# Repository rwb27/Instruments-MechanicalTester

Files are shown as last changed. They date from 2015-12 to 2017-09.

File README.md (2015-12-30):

# OpenLabTools Mechanical Testing Machine

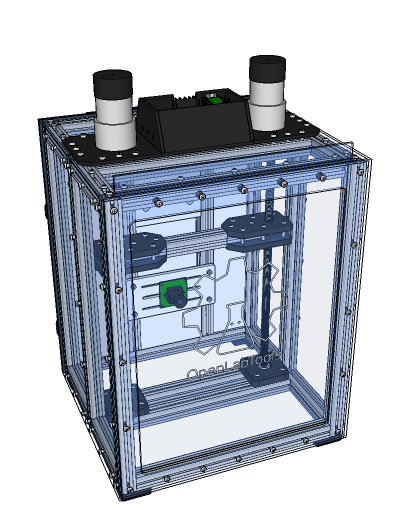
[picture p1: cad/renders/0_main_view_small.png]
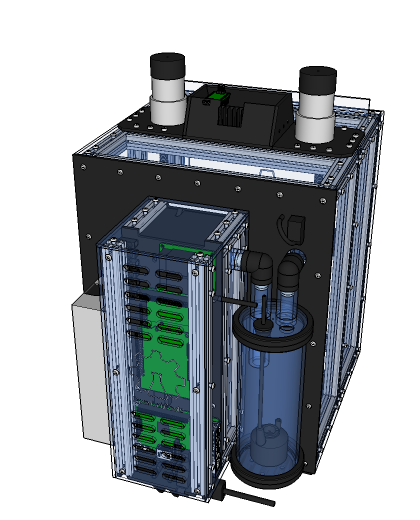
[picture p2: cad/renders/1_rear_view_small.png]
 

This is the repository for an open source mechanical testing machine with environmental control. A double glazed enclosure is built using OpenBeam extrusion and clear plastic panels as outlined [here](https://github.com/OpenLabTools/Resources-EnvironmentalChambers). Humidity control is achieved with a reservoir/chamber, ultrasonic mister, fan driven air flow and a servo controlled flap/valve. This is discussed further [here](https://github.com/OpenLabTools/Resources-HumidityControl). Temperature control is achieved using the same fan driven air flow system, resistive heating and multiple DS18B20 digital temperature sensors. This approach and alternatives to it are discussed [here](https://github.com/OpenLabTools/Resources-TemperatureControl).

Documentation for the instrument, including assembly instructions and discussion are [here](docs/00-getting_started.md).

This instrument was created by [@rob-eager](https://github.com/rob-eager) in 2014-15 as an MEng final year project and is currently being documented. It also has a Github Pages [page](http://openlabtools.github.io/Instruments-MechanicalTester/) under development.

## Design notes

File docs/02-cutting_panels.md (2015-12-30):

### OpenLabTools Materials Tester Documentation
- [Getting Started](\00-getting_started.md)
- [Sourcing Components](\01-sourcing_components.md)
- **Cutting Panels**
- [Assembly Step 01 - Front Enclosure](\03-assembly-01_front_enclosure.md)
- [Assembly Step 02 - Rear Face](\03-assembly-02_rear_face.md)
- [Assembly Step 03 - Rear Module](\03-assembly-03_rear_module.md)
- [Assembly Step 04 - Electronics](\03-assembly-04_electronics.md)
- [Assembly Step 05 - Motors](\03-assembly-05_motors.md)
- [Installing Software](\04-installing_software.md)
- [Commissioning](\05-commissioning.md)
- [Designing An Experiment](\06-designing_an_experiment.md)
- [Running An Experiment](\07-running_an_experiment.md)
- [Maintenance](\08-maintenance.md)
- [Customisation](\09-customisation.md)
- [Performance](\10-performance.md)

### Cutting Panels

[//]: # (END TITLE BLOCK)

Placeholder content

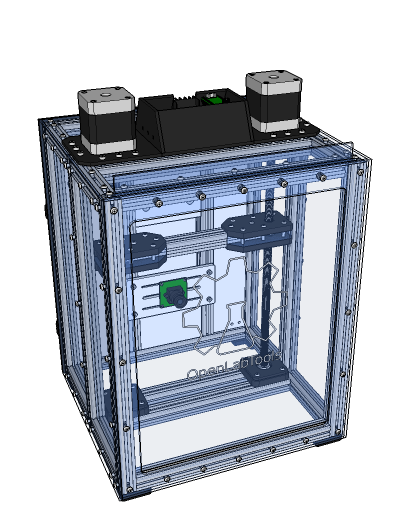
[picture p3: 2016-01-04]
cad/renders/6_main_view_stepper_motors_small.png

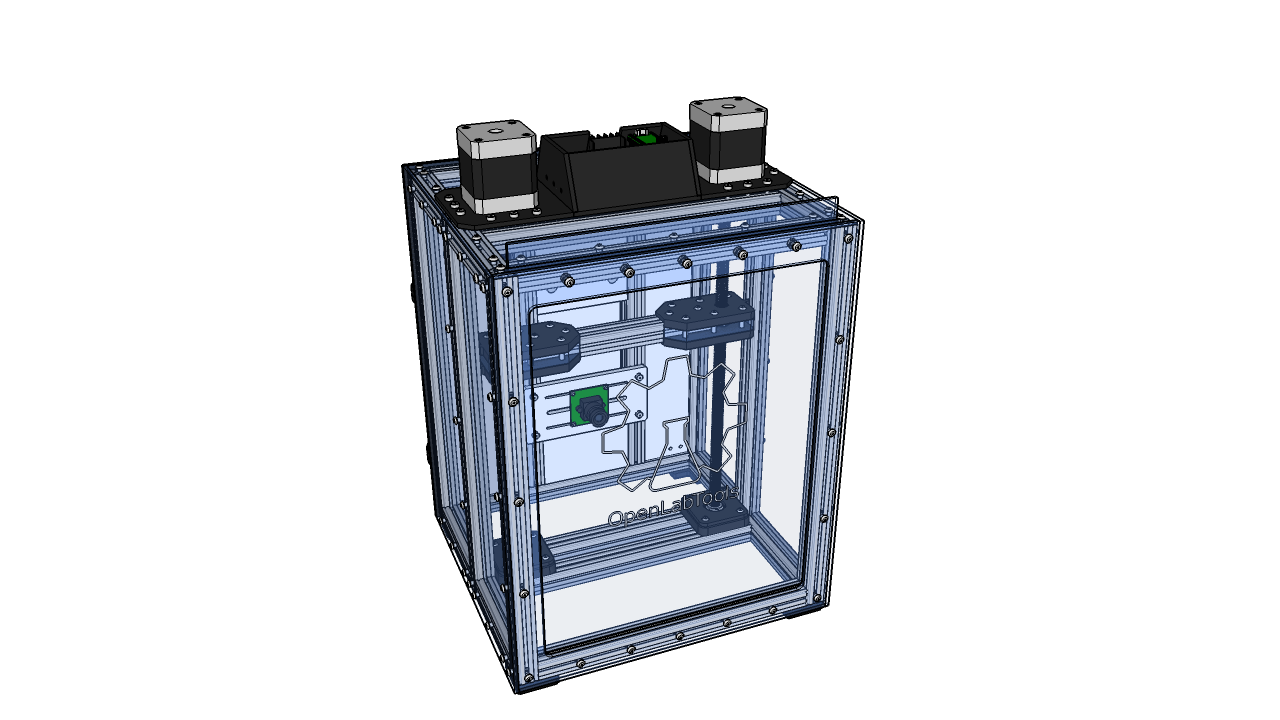
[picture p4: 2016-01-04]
cad/renders/6_main_view_stepper_motors.png

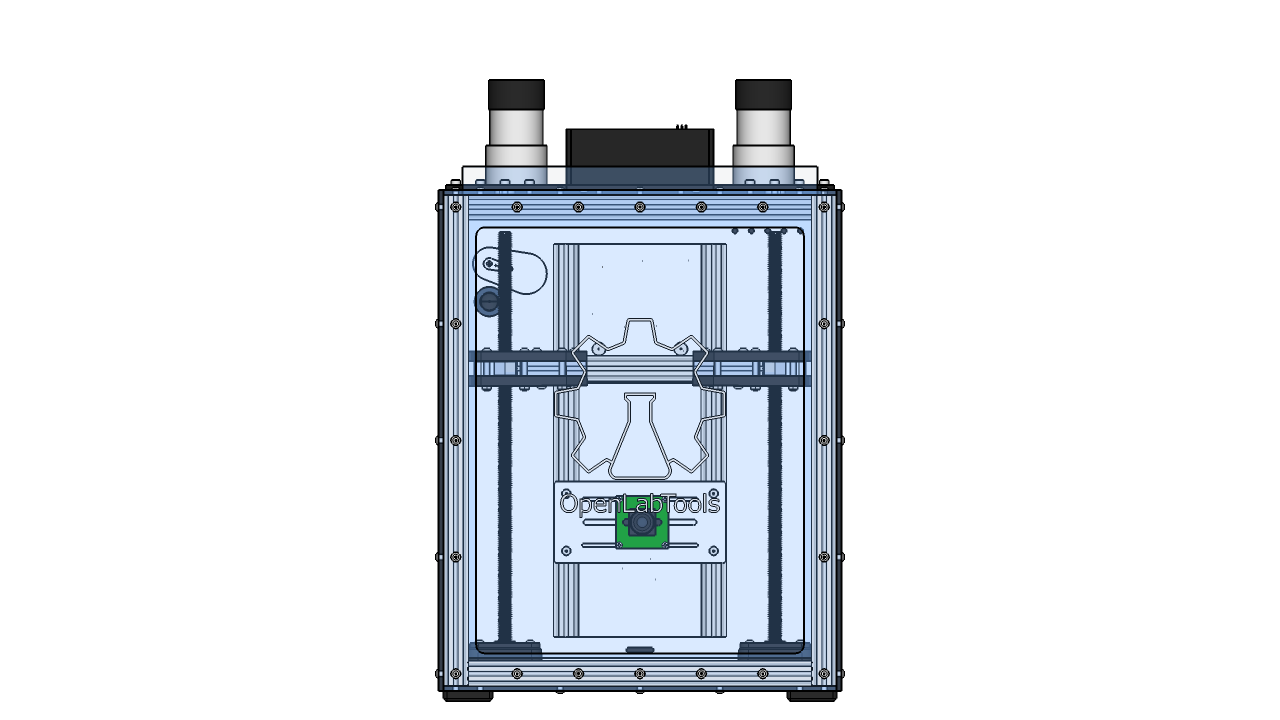
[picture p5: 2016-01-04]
cad/renders/3_front.png

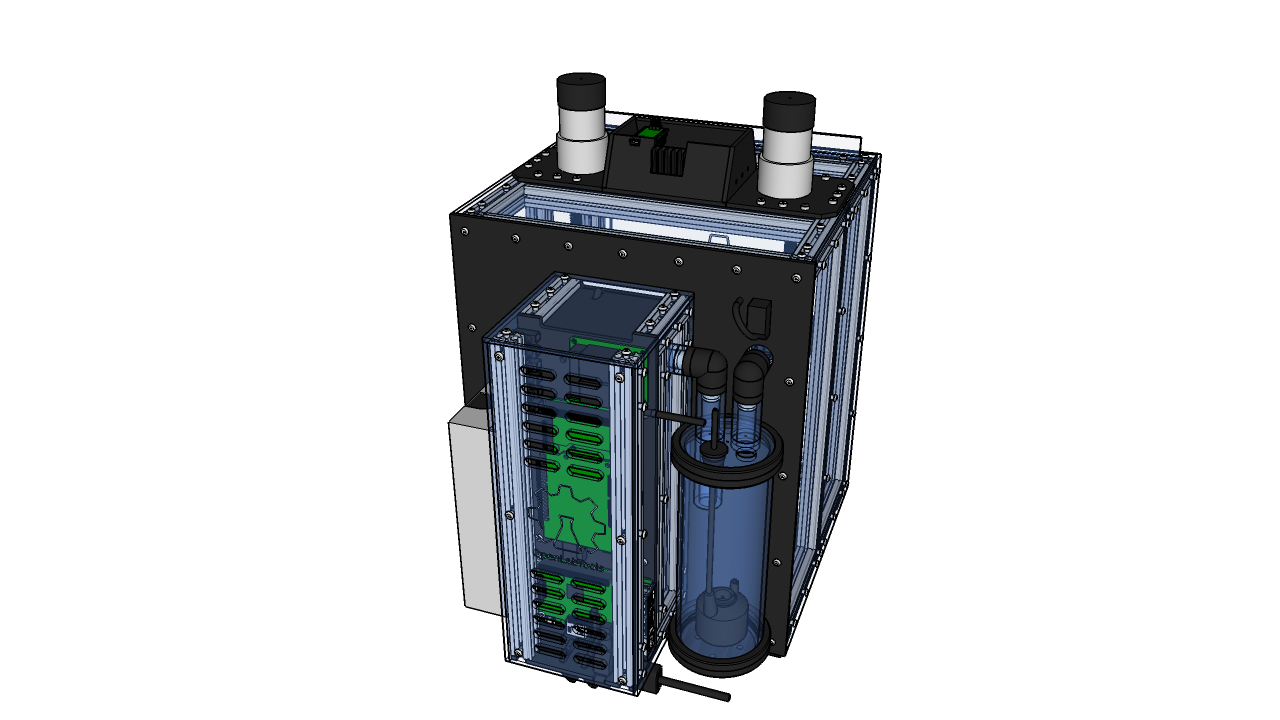
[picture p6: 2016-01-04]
cad/renders/1_rear_view.png

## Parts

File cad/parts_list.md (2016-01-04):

1x Assembly - Arduino Stack
2x Assembly - Baffle
1x Assembly - Bottom Face
1x Assembly - Camera Mount
1x Assembly - Electronics
1x Assembly - Front Face
1x Assembly - Front Module
1x Assembly - Full
1x Assembly - Heater Elements
1x Assembly - Humidity Chamber
1x Assembly - Humidity Tube Inlet
1x Assembly - Humidity Tube Outlet
1x Assembly - Main Instrument
1x Assembly - Materials Testing
2x Assembly - Motor, Lead Screw and Bearing
1x Assembly - Rear Face
1x Assembly - Rear Module
1x Assembly - Rear Module Back Face
1x Assembly - Rear Module Bottom
1x Assembly - Rear Module Humidity Side Wall
1x Assembly - Rear Module PSU Side Wall
1x Assembly - Rear Module Top
1x Assembly - Servo Flap
2x Assembly - Side Wall
1x Assembly - Top Face
1x Assembly - Top Module
4x Fixings - M2.5 PAN
8x Fixings - M3 Button Screw 15mm
8x Fixings - M3 Button Screw 15mm and Nut
12x Fixings - M3 Button Screw 24mm
12x Fixings - M3 Button Screw 24mm and Nut
212x Fixings - M3 Button Screw 6mm
195x Fixings - M3 Button Screw 6mm and Nut
50x Fixings - M3 Cap Screw 10mm
30x Fixings - M3 Cap Screw 10mm and Nut
249x Fixings - M3 Nut
2x Fixings - M3 Wing Nut
8x Fixings - M4 CSK 16mm
4x Fixings - M4 CSK 26mm
4x Fixings - M4 CSK 50mm
16x Fixings - M4 Nut
4x Fixings - M8 Half Nut
2x Fixings - M8 Nut
1x Panel - Back Face
2x Panel - Baffle Front Plate
2x Panel - Baffle Mount
6x Panel - Baffle Spacer
2x Panel - Bearing Top
2x Panel - Bottom Double Glazing
1x Panel - Bottom Double Glazing Middle
1x Panel - Bottom Face
1x Panel - Camera Mounting Plate
2x Panel - DC Motor Mount
4x Panel - Delrin Plate
1x Panel - Fan Mounting
1x Panel - Front Door
1x Panel - Front Frame
2x Panel - Gantry Spacer
1x Panel - HDMI support 1
1x Panel - HDMI support 2
2x Panel - Heater Reflector Plate
1x Panel - Humidity Chamber Top Face
1x Panel - Humidity End Cap
1x Panel - Humidity Rubber Bumper Bottom
2x Panel - Humidity Rubber Bumper Middle
1x Panel - Humidity Rubber Bumper Top
1x Panel - Humidity Support
1x Panel - Inner Back Wall
2x Panel - NEMA 17 mount
2x Panel - NEMA 23 mount
1x Panel - Rear Module Back Double Glazing
1x Panel - Rear Module Back Face
1x Panel - Rear Module Bottom Face
1x Panel - Rear Module Electronics
1x Panel - Rear Module Humidity Side
1x Panel - Rear Module Humidity Side Double Glazing
1x Panel - Rear Module PSU Side
1x Panel - Rear Module PSU Side Double Glazing
1x Panel - Rear Module Top Face
2x Panel - Rear Module Top and Bottom Double Glazing
1x Panel - Rubber Humidity Bung
1x Panel - Servo Flap
2x Panel - Side
4x Panel - Side Double Glazing
1x Panel - Top Double Glazing Back
1x Panel - Top Double Glazing Front
1x Panel - Top Double Glazing Middle
1x Panel - Top Face
1x Panel - Top Module Back
1x Panel - Top Module Bottom
1x Panel - Top Module Front
2x Panel - Top Module Side
2x Part - 608 skate bearing
2x Part - 60mm Fan
1x Part - Arduino DUE
1x Part - Arduino Metro
1x Part - Arduino Shield
2x Part - Back Foot
1x Part - Choc Bloc
2x Part - DC MotorWith Encoder
1x Part - DFROBOT USB Touch Screen
2x Part - DS18B20 Temperature Sensor
2x Part - Fan Blades
1x Part - Flap Servo
2x Part - Front Foot
1x Part - HDMI Flat 90
1x Part - HDMI Plug
1x Part - Header 1x15
1x Part - Header 1x15#1
1x Part - Header 2x3
1x Part - Humidity Tube
1x Part - Inlet Tube Horizontal
1x Part - Inlet Tube Vertical
2x Part - M8 Lead Screw
1x Part - Motor Driver
2x Part - Nema 17 stepper motor
1x Part - OpenBeam 150mm
12x Part - OpenBeam 210mm
4x Part - OpenBeam 240mm
6x Part - OpenBeam 300mm
6x Part - OpenBeam 60mm
8x Part - OpenBeam 90mm
2x Part - OpenBeam Bearing Mount
1x Part - Outlet Tube Horizontal
1x Part - Outlet Tube Vertical
1x Part - PSU
1x Part - Raspberry Pi Camera
1x Part - Raspberry Pi Model B
1x Part - Relay Board
1x Part - Servo Horn
2x Part - Servo Motor
2x Part - Shaft Coupler
1x Part - Small Fogger
4x Part - Tube Coupler
2x Part - Tube Elbow
1x Part - USB OTG Cable

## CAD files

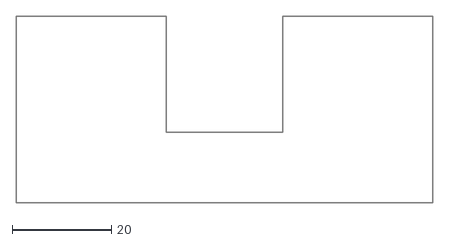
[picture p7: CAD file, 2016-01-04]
cad/panels/dxf_files/top_module_back.dxf
84.0 x 37.6

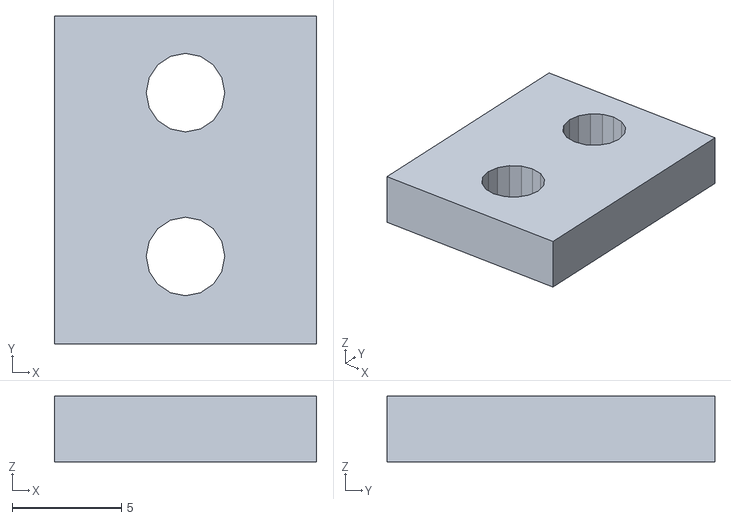
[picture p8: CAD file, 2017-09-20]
cad/parts/load_cell_spacer_M3.stl
12.0 x 15.0 x 3.00

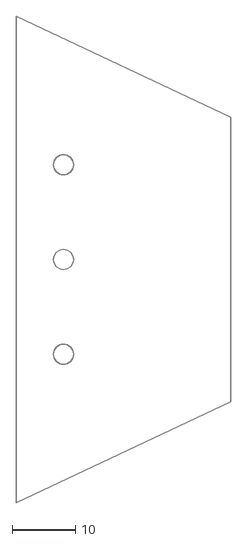
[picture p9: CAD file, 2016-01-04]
cad/panels/dxf_files/top_module_side.dxf
34.0 x 77.0

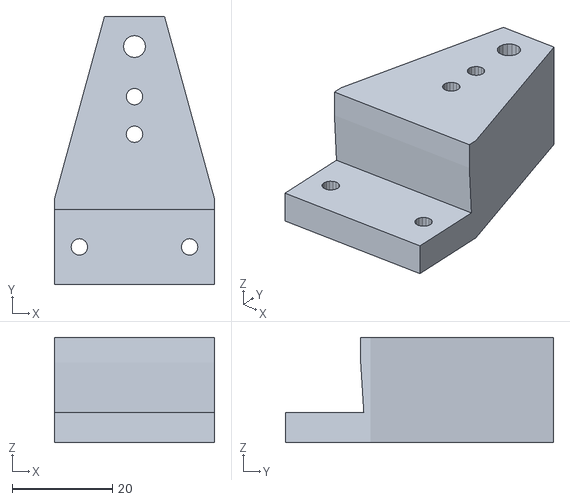
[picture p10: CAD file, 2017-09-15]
cad/parts/load_cell_mount_tension.stl
32.0 x 53.5 x 21.0

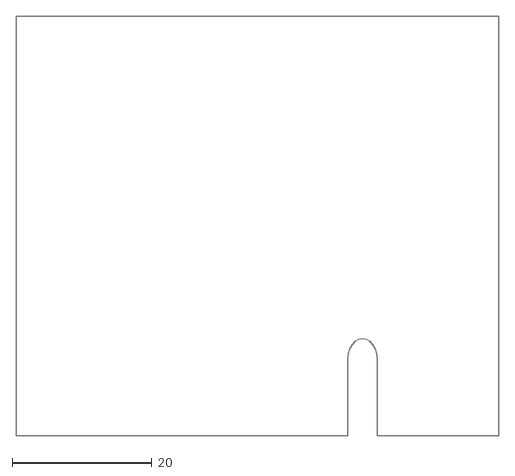
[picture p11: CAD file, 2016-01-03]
cad/panels/dxf_files/rear_module_top_and_bottom_double_glazing.dxf
69.0 x 60.0

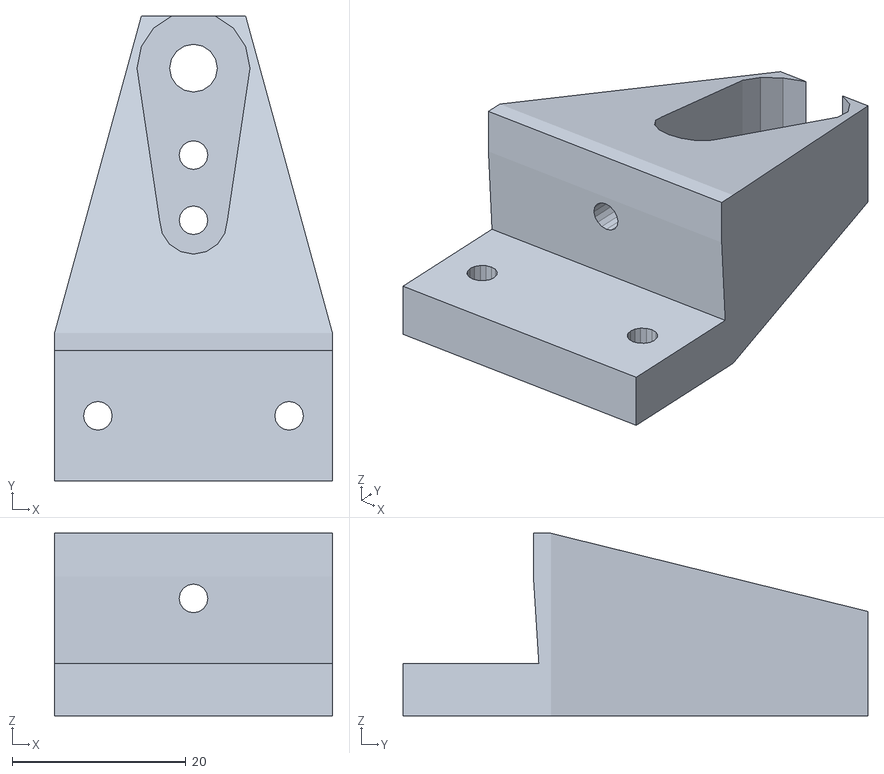
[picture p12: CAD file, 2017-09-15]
cad/parts/load_cell_mount.stl
32.0 x 53.5 x 21.0

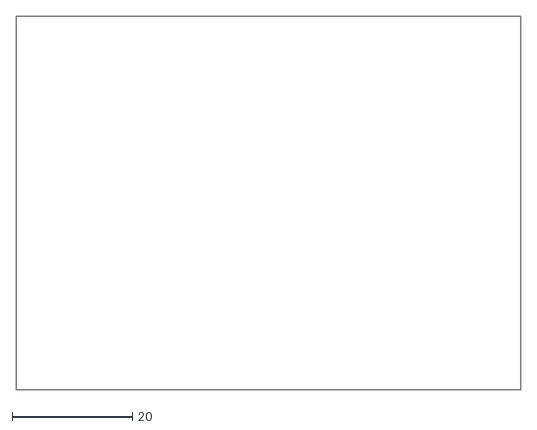
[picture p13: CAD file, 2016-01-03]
cad/panels/dxf_files/top_module_front.dxf
84.0 x 62.2

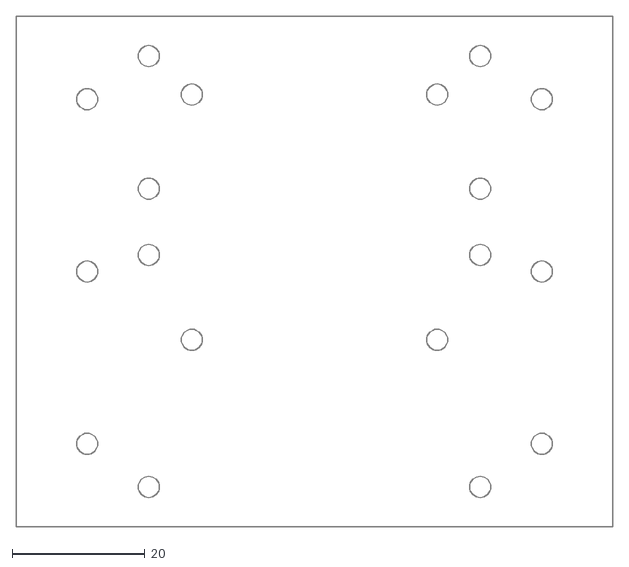
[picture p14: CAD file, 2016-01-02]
cad/panels/dxf_files/top_module_bottom.dxf
90.0 x 77.0

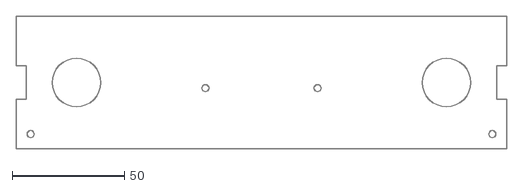
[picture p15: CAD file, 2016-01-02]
cad/panels/dxf_files/top_double_glazing_middle.dxf
219.0 x 59.0

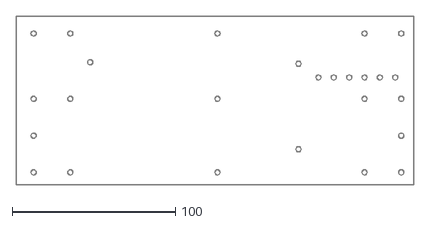
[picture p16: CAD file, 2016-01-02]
cad/panels/dxf_files/rear_module_psu_side.dxf
243.0 x 103.0

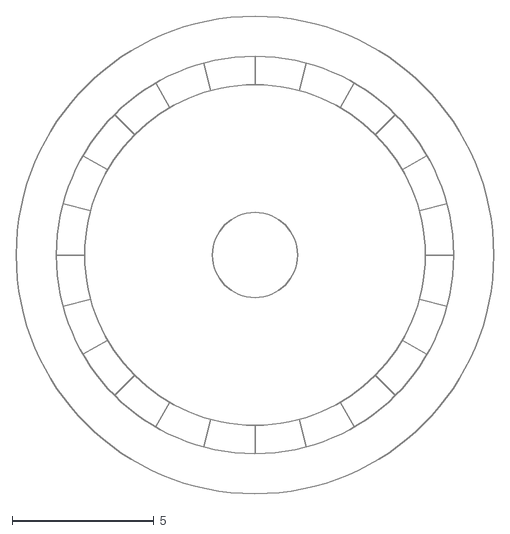
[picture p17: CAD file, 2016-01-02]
cad/panels/dxf_files/rubber_humidity_bung.dxf
16.8 x 16.8

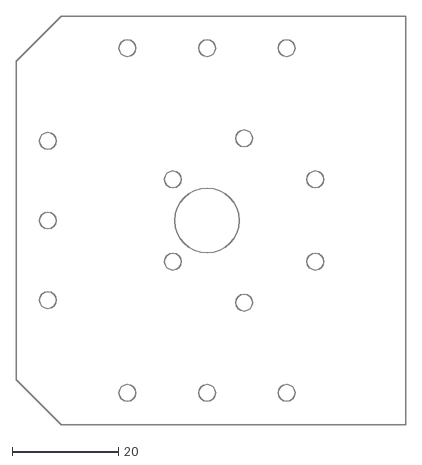
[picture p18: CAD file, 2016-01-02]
cad/panels/dxf_files/dc_motor_mount.dxf
73.5 x 77.0

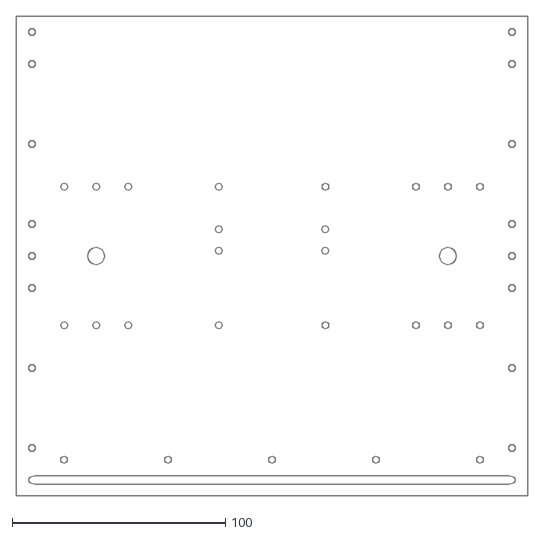
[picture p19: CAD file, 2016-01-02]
cad/panels/dxf_files/top_face.dxf
240.0 x 225.0

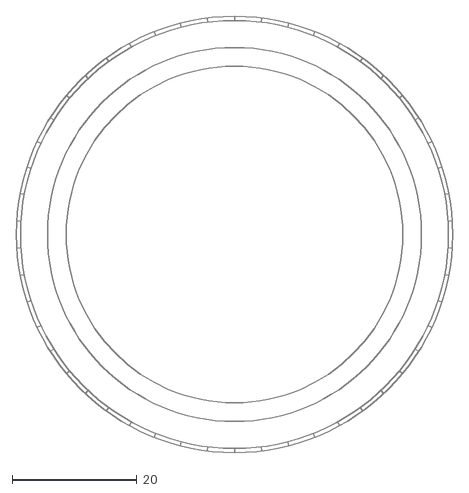
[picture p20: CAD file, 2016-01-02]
cad/panels/dxf_files/humidity_rubber_bumper_top.dxf
70.0 x 70.0

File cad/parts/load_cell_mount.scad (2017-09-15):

// A basic mount to attach a load cell to an OpenBeam strut
// The load cell is at 90 degrees to the strut, with its hole
// in line with the centre of the strut.
// This is designed for Phidgets 3132, 3133 and 3134 load cells

holes = [[5, 40], [3, 30], [3, 22.5]];
cell_w = 12;
mount_w = cell_w + 20;
ob = 15; //openbeam size
t = 6; //thickness of mount
$fn=16;

difference(){
    union(){
        hull(){
            for(h=holes) translate([0,h[1],6]) cube(12, center=true);
            //for(h=holes) translate([0,h[1],ob+t-6]) cube(12, center=true); //uncomment for tension mount
            
            translate([-mount_w/2,ob/2+1,0]) cube([mount_w, 1, 12]);
            translate([-mount_w/2, ob/2, ob-5+t]) cube([mount_w, 2, 5]);
        }
        translate([-mount_w/2, -ob/2, 0]) cube([mount_w, ob+2, t]);
    }
    
    //mounting holes
    //translate([0,0,ob+t]) mirror([0,0,1]) //uncomment for tension
    union(){
        for(h=holes) translate([0,h[1],-99]) cylinder(d=h[0]*1.1, h=999);
        hull() for(h=holes){
            translate([0,h[1],t]) cylinder(r=h[0]*1.3, h=999);
        }
    }
    
    for(d=[-1,1]) translate([d*(cell_w/2+5), 0, -99]) cylinder(d=3*1.1,h=999);
        
    //this allows the "compression" version to do tension too
    translate([0, ob/2+t, ob/2+t]) rotate([-90,0,0]){
        translate([0,0,-99]) cylinder(d=3*1.1, h=99+1);
        cylinder(r=3*1.3, h=holes[0][1]-ob/2-t);
    }
}
    

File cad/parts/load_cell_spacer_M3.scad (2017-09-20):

$fn=16;
difference(){
    translate([-6,0,0]) cube([12,15,3]);
    
    translate([0,4,-1]) cylinder(d=3.6,h=99);
    translate([0,4+7.5,-1]) cylinder(d=3.6,h=99);
}

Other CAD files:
cad/vectors/panels/Rear Module Back Face#1.dxf
cad/parts/load_cell_mount_compression.stl
cad/panels/dxf_files/servo_flap.dxf
cad/panels/dxf_files/humidity_rubber_bumper_middle.dxf
cad/panels/dxf_files/back_face.dxf
cad/panels/dxf_files/baffle_front_plate.dxf
cad/panels/dxf_files/baffle_mount.dxf
cad/panels/dxf_files/baffle_spacer.dxf
cad/panels/dxf_files/bearing_top.dxf
cad/panels/dxf_files/bottom_double_glazing.dxf
cad/panels/dxf_files/bottom_double_glazing_middle.dxf
cad/panels/dxf_files/bottom_face.dxf
cad/panels/dxf_files/camera_mounting_plate.dxf
cad/panels/dxf_files/delrin_plate.dxf
cad/panels/dxf_files/fan_mounting.dxf
cad/panels/dxf_files/front_door.dxf
cad/panels/dxf_files/front_frame.dxf
cad/panels/dxf_files/gantry_spacer.dxf
cad/panels/dxf_files/hdmi_support_1.dxf
cad/panels/dxf_files/hdmi_support_2.dxf
cad/panels/dxf_files/heater_reflector_plate.dxf
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

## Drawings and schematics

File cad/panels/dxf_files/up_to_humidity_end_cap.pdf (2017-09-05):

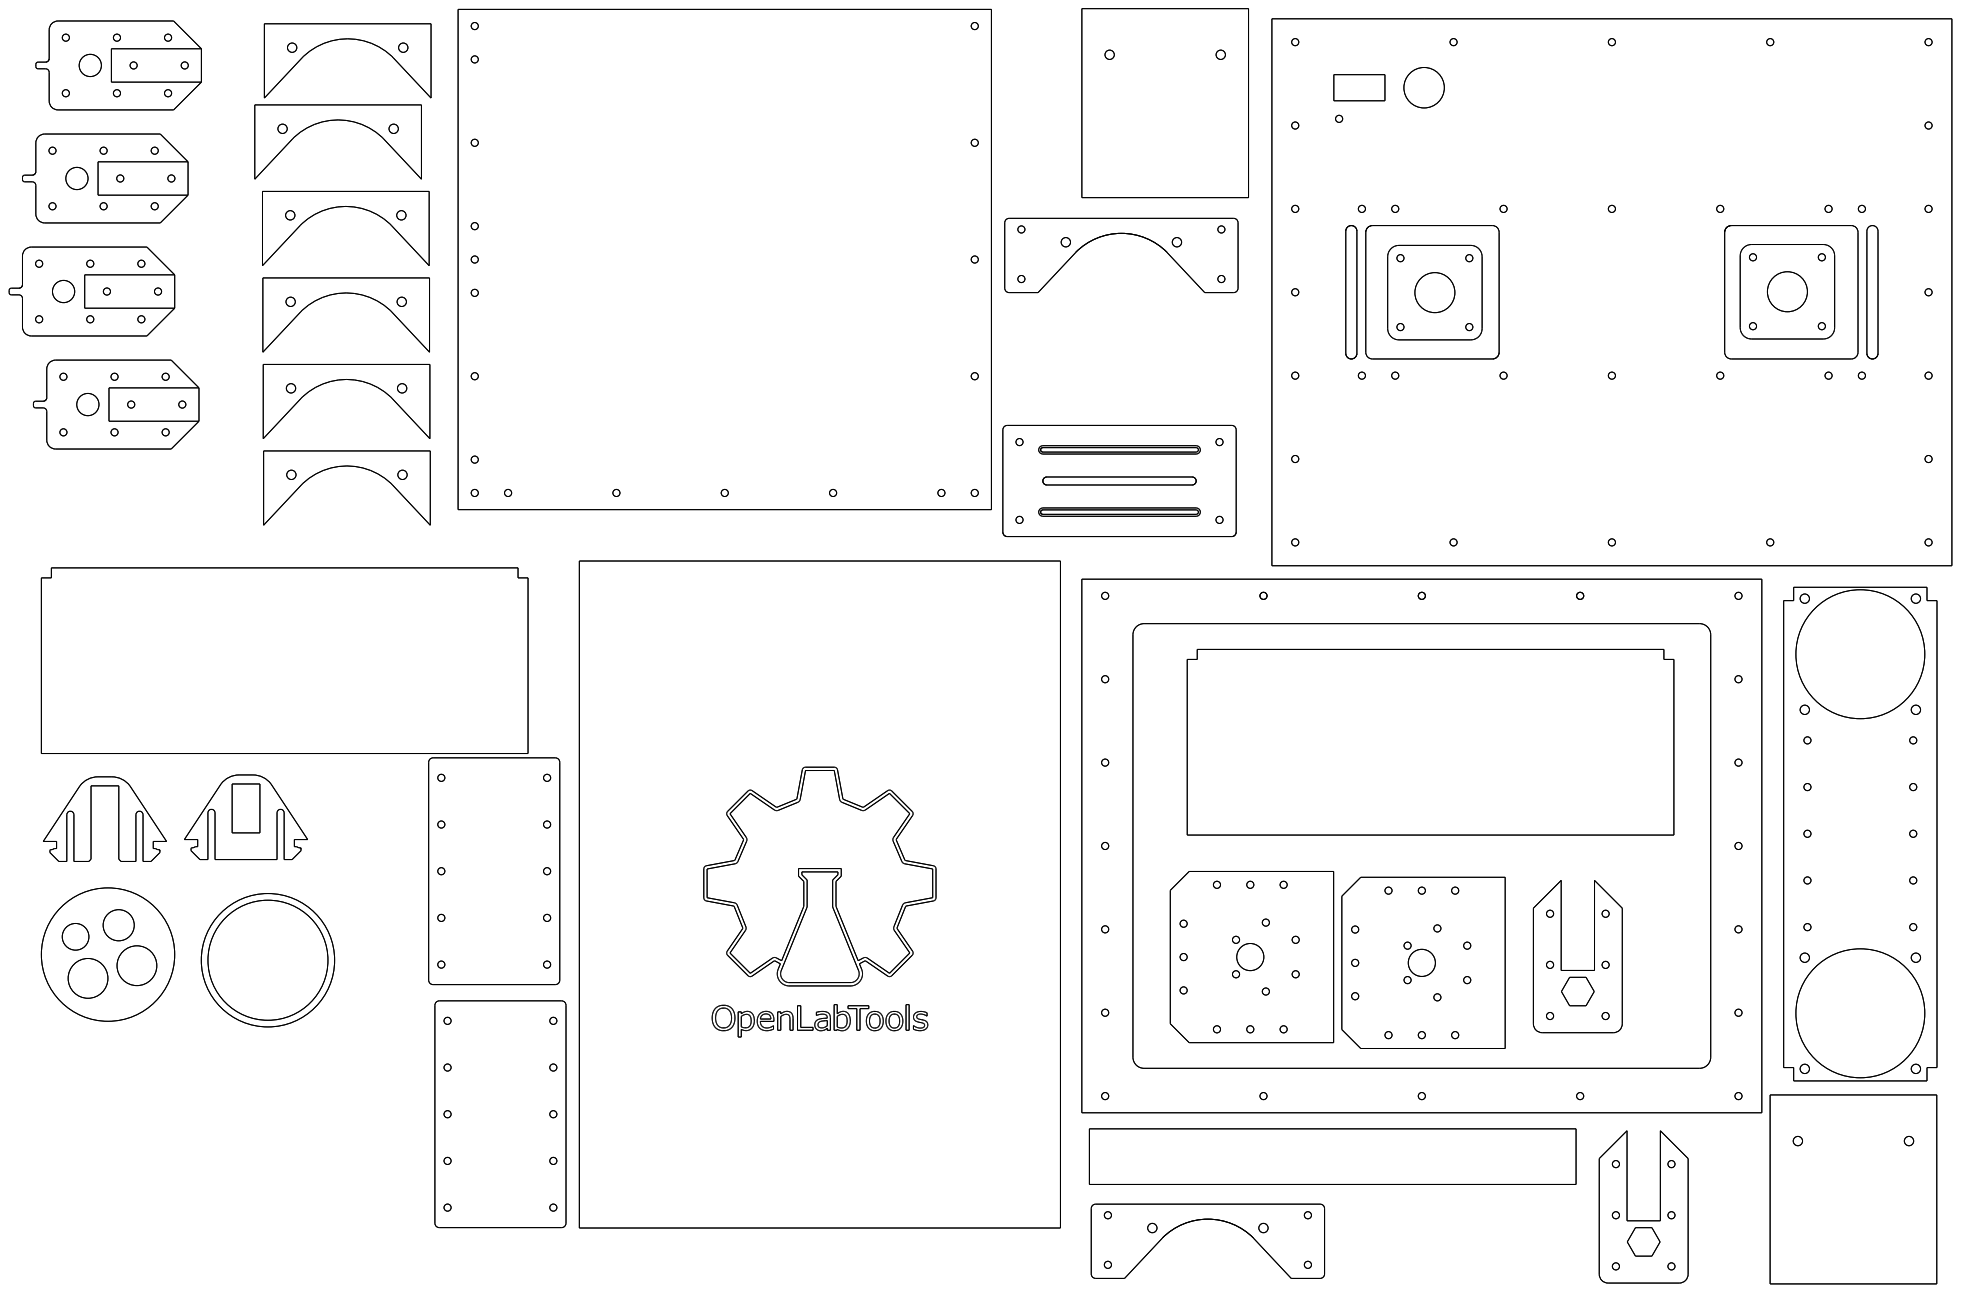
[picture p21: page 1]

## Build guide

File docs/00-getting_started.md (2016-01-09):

### OpenLabTools Materials Tester Documentation
- **Getting Started**
- [Sourcing Components](\01-sourcing_components.md)
- [Cutting Panels](\02-cutting_panels.md)
- [Assembly Step 01 - Front Enclosure](\03-assembly-01_front_enclosure.md)
- [Assembly Step 02 - Rear Face](\03-assembly-02_rear_face.md)
- [Assembly Step 03 - Rear Module](\03-assembly-03_rear_module.md)
- [Assembly Step 04 - Electronics](\03-assembly-04_electronics.md)
- [Assembly Step 05 - Motors](\03-assembly-05_motors.md)
- [Installing Software](\04-installing_software.md)
- [Commissioning](\05-commissioning.md)
- [Designing An Experiment](\06-designing_an_experiment.md)
- [Running An Experiment](\07-running_an_experiment.md)
- [Maintenance](\08-maintenance.md)
- [Customisation](\09-customisation.md)
- [Performance](\10-performance.md)

### Getting Started

[//]: # (END TITLE BLOCK)

There are really two options for assembling an instrument. In some cases it should be possible to just procure the parts needed and get the panels cut from the provided outline files. Even though generic components have been used as far as possible some of them may be hard to procure exact copies of. If replacements need to be used then some tweaks to the panels/mounting options may be required. It is also likely that some users may wish to tailor the instrument to their specific needs. In these cases the source Sketchup model and an export script for generating the revised parts list and panels is provided.

Additionally during assembly it may well be useful to be able to explore the Sketchup model to check things are assembled as described.

### Cloning the Instrument Repository

GitHub provides [instructions](https://help.github.com/articles/cloning-a-repository/) for cloning a repository. For someone inexperienced with Git, the GitHub Desktop approach makes everything very easy - just make sure you're signed in to both GitHub in your browser and GitHub Desktop when you click the clone URL it describes. It's easy to forget to sign in to GitHub in the browser which will cause the browser link to just redirect to a page for installing GitHub Desktop. Only when you're logged in to both will the process work correctly. If you're still getting redirected to the install page then the link between the two is still not established, try logging out and in again in both places and reinstalling GitHub Desktop. Failing that Google is your friend!

### Installing Sketchup

Sketchup Make is free to [download and install](http://www.sketchup.com/download).

### Running the Build Script

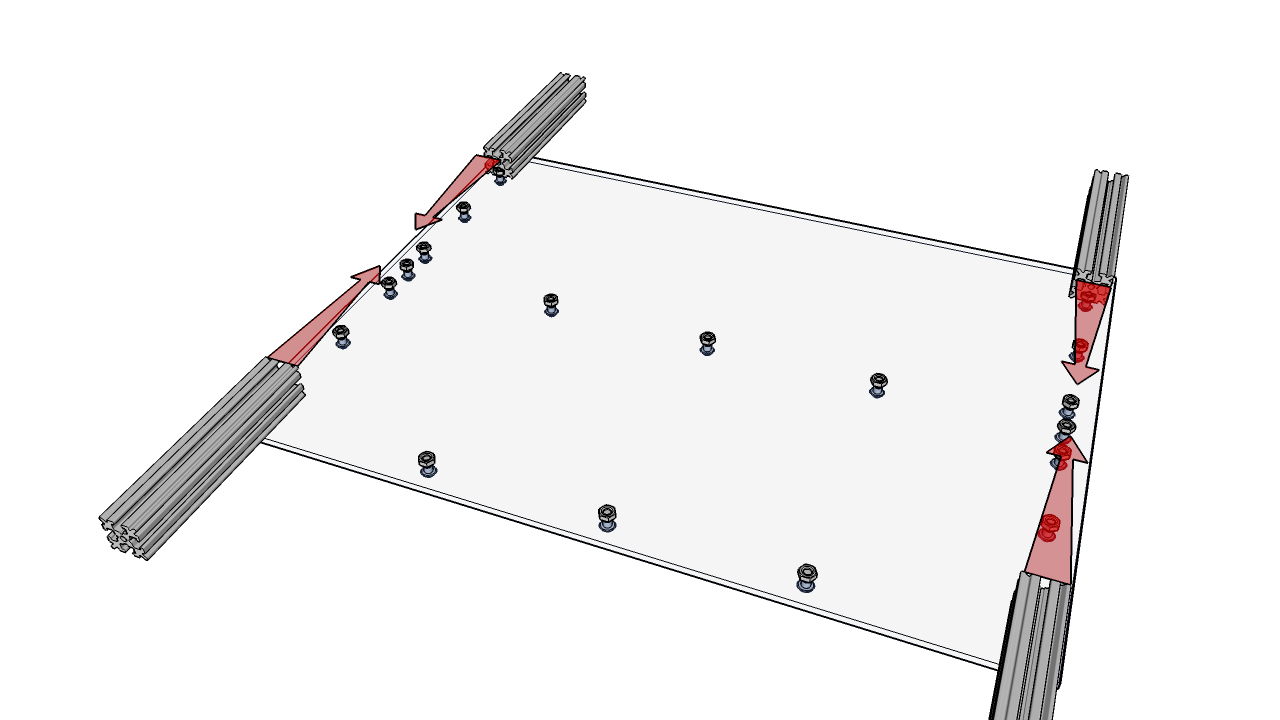
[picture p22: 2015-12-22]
cad/subassemblies/side_wall/renders/2_add_horizontals.png

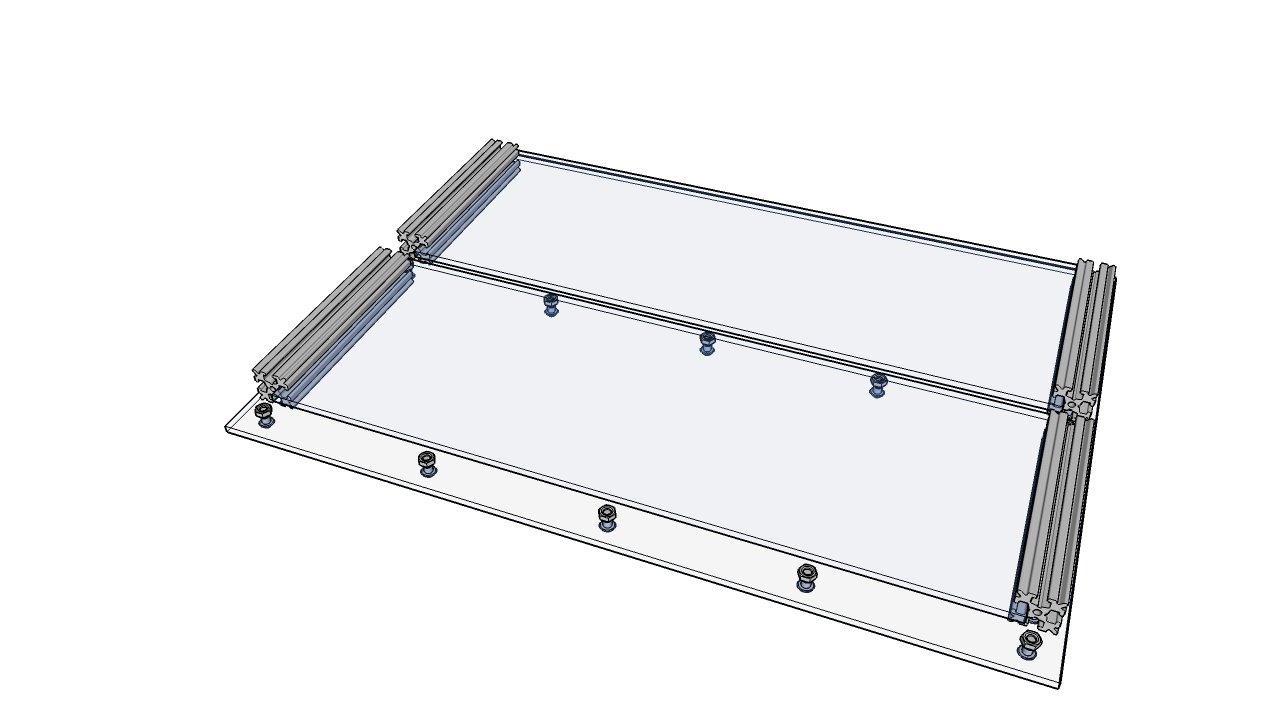
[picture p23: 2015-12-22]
cad/subassemblies/side_wall/renders/5_add_double_glazing_done.png

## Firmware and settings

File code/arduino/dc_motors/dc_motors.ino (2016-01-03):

#include <SerialCommand.h>
SerialCommand NanoCmd;   // The Nano Subsystem SerialCommand object

// connect encoder and motor controller pins to Arduino digital pins
  int GantryTarget = 0;
  // Motor 0
  int M0_pwm = 5;
  int M0_dir_1 = 3;
  int M0_dir_2 = 4;
  int M0_encoder_A = 9;
  int M0_encoder_B = 10;
  int M0_pos = 0;
  int M0_encoder_A_last = HIGH;
  int M0_delta = 0;
  // Motor 1
  int M1_pwm = 6;
  int M1_dir_1 = 7;
  int M1_dir_2 = 8;
  int M1_encoder_A = 11;
  int M1_encoder_B = 12;
  int M1_pos = 0;
  int M1_encoder_A_last = HIGH;
  int M1_delta = 0;


// set up encoder variables
  int n = LOW;
  int m = LOW;
  int dir_0;
  int dir_1;
  int power_0;
  int power_1;

void setup() {
  Serial.begin (115200);
  // Setup callbacks for SerialCommand commands
  NanoCmd.addCommand("G",  GantryMove);   // moves test gantry +ve up -ve down
  //   NanoCmd.setDefaultHandler(unrecognized_params);

  // set all the motor control pins to outputs
  pinMode(M0_pwm, OUTPUT);
  pinMode(M1_pwm, OUTPUT);
  pinMode(M0_dir_1, OUTPUT);
  pinMode(M0_dir_2, OUTPUT);
  pinMode(M1_dir_1, OUTPUT);
  pinMode(M1_dir_2, OUTPUT);

  //initialise encoder pins
  pinMode (M0_encoder_A, INPUT);
  pinMode (M0_encoder_B, INPUT);
  pinMode (M1_encoder_A, INPUT);
  pinMode (M1_encoder_B, INPUT);


}
void set_motors() {
  M0_delta =  (GantryTarget - M0_pos);
  M1_delta =  (GantryTarget - M1_pos);

  if (M0_delta >= 0) dir_0 = HIGH;
  else               dir_0 = LOW;
  if (M1_delta >= 0) dir_1 = HIGH;
  else               dir_1 = LOW;

  if (abs(M0_delta) > 105) power_0 = 255;
  else                     power_0 = abs(M0_delta) + 150;
  if (abs(M1_delta) > 105) power_1 = 255;
  else                     power_1 = abs(M1_delta) + 150;
  
  if (abs(M0_delta) <= 1) power_0 = 0;
  if (abs(M1_delta) <= 1) power_1 = 0;
  digitalWrite(M0_dir_1, !dir_0);
  digitalWrite(M0_dir_2,  dir_0);
  digitalWrite(M1_dir_1, !dir_1);
  digitalWrite(M1_dir_2,  dir_1);
  analogWrite( M0_pwm,  power_0);
  analogWrite( M1_pwm,  power_1);
}

void loop() {
  NanoCmd.readSerial();
  GetEncoders();
  set_motors();
}

void GetEncoders() {
  n = digitalRead(M0_encoder_A);
  m = digitalRead(M1_encoder_A);
  if ((M0_encoder_A_last == LOW) && (n == HIGH)) {
    if (digitalRead(M0_encoder_B) == LOW) M0_pos--;
    else M0_pos++;
  }
  if ((M1_encoder_A_last == LOW) && (m == HIGH)) {
    if (digitalRead(M1_encoder_B) == LOW) M1_pos--;
    else M1_pos++;
  }
  if (((M0_encoder_A_last == LOW) && (n == HIGH)) || ((M1_encoder_A_last == LOW) && (m == HIGH))) {
    Serial.print (M0_delta);
    Serial.print ("/");
    Serial.println (M1_delta);
  }
  M0_encoder_A_last = n;
  M1_encoder_A_last = m;
  // TODO Get time stamp
}

void GantryMove() {
  int aNumber;
  char *arg;

  Serial.println("Adjusting Gantry");
  arg = NanoCmd.next();
  if (arg != NULL) {
    GantryTarget = atoi(arg);    // Converts a char string to an integer
    Serial.print("Gantry Steps: ");
    Serial.println(GantryTarget);
  }
  else {
    Serial.println("No arguments");
  }
}

void unrecognized_params() {
  // This gets set as the default handler, and gets called when no other command matches.
  Serial.println("What?");
}

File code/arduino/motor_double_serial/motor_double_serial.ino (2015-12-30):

// Serial connections for servos:
// Brown    - +5V
// Red      - +5V
// Orange   - RXD 2
// Yellow   - TXD 3
// Orange 2 - RXD 4
// Yellow 2 - TXD 5

#include <SoftwareSerial.h>

SoftwareSerial motor_R(2, 3); // RX, TX
SoftwareSerial motor_L(4, 5); // RX, TX


void print_binary(int v, int num_places)
{
  int mask = 0, n;
  for (n = 1; n <= num_places; n++) mask = (mask << 1) | 0x0001;
  v = v & mask;  // truncate v to specified number of places
  while(num_places) {
    if (v & (0x0001 << num_places - 1)) Serial.print("1");
    else Serial.print("0");
    --num_places;
  }
}

void setup() {
  Serial.begin(9600);
  motor_R.begin(9600);
  motor_L.begin(9600);
  Serial.println("setup complete");
}

void loop() {
  if (Serial.available()) {
    delay(10);
    char motor = Serial.read();
    char c;
    switch(motor) {
    case 'R':
      Serial.print("\nright motor command: ");
      motor_R.listen();
      while (Serial.available()) {
        c = Serial.read();
        Serial.write(c);
        motor_R.write(c);
      }
      delay(50);
      while (motor_R.available()) {
        delay(50);
        c = motor_R.read();
        Serial.write(c);
        Serial.print("(");
        print_binary(c, 8);
        Serial.print(") ");
        delay(50);
      }
      break;
    case 'L':
      Serial.print("\nleft motor command:  ");
      motor_L.listen();
      while (Serial.available()) {
        c = Serial.read();
        Serial.write(c);
        motor_L.write(c);
      }
      delay(50);
      while (motor_L.available()) {
        delay(50);
        c = motor_R.read();
        Serial.write(c);
        Serial.print("(");
        print_binary(c, 8);
        Serial.print(") ");
        delay(50);
      }
      break;
    default:
      while (Serial.available()) Serial.read();
    }
  }
  motor_R.listen();
  delay(50);
  if (motor_R.available()) {
    Serial.print("Right: ");
    delay(50);
    while (motor_R.available()) {
      Serial.write(motor_R.read());
      delay(50);
    }
  }
  motor_L.listen();
  delay(50);
  if (motor_L.available()) {
    Serial.print("Left:  ");
    delay(50);
    while (motor_L.available()) {
      Serial.write(motor_L.read());
      delay(50);
    }
  }
}

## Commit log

2015-11-12 Initial CAD commit of main structure
    Main structural beams, outer glazing panels, sliding door, motors, lead
    screws and couplers
2015-11-12 Added rear wall
    Rear Wall with mounting screws, fan holes, cable ports, flap servo and
    humidity tube
2015-11-13 Added PSU CAD model
    Added CAD model of the Seasonic SS-250SU PSU
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2015-11-13 Added rear module panels and M3 nuts
    Rear module top and bottom, inner and outer panels added. Distinction
    created for difference between bolts into channels (with nuts) vs. into
    end of beams (no nut)
2015-11-14 Added inner chamber wall, electronics mounting panel, rear module rear panel and hole and bolt details
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2015-11-16 Revert "Component renaming/standardisation, humidity chamber, back face details"
    This reverts commit c2b96251406530ea5a3fa000e9a41db09eb97f11.
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2015-11-17 Added humidity chamber lid and resolved alignment errors
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2015-11-21 Major rework - electronics module, motors and gantry
    Swap to full sized raspberry pi (B+/2) and rotate so USB and ethernet
    come out the humidity chamber side, use 90 degree HDMI adaptor to bring
    cable horizontally out the bottom of the module to match USB, ethernet
    and power. Move to Arduino with micro USB programming port to save space
    with plan to use a short 90 degree USB OTG cable to bring the
    programming port out to the humidity side to allow programming by
    plugging from Pi USB to Arduino USB while usually just having a wired
    serial link between GPIO. Overall more space created in rear module and
    more USB sockets available on the outside so a USB hub is no longer
    needed. Added NEMA 23 s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
2015-11-24 Added standard materials, corrected motor alignment, removed rear module holes, split motor mounting plate
    Whole model coloured with standard materials, very slight discrepancy
    between motor mounting fixed (<0.1mm now exactly 160mm axis separation),
    in real use the rear panel and module are frequently removed and the row
    of fixing holes are unused - only 2 fixings top and bottom used, two
    separate versions of the motor mounting plate, one with holes for NEMA
    17 and the other for NEMA 23.
2015-11-24 Added gantry details and added correct feet model
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2015-11-26 Added nuts and bolts for gantry ends, baffles, camera, camera mount and bearing mounts
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2015-12-06 Initial commit of management/vector export script
    Script saves itself in to repo and currently generates a parts list.
    When complete it will save vector outlines of the parts that need
    machining
2015-12-09 Large update to export script + improve panel names
    Added large chunk of dxf output to export script. Works well on some
    panels while others it jumbles.
    [Back Face.dxf, Baffle Front Plate.dxf, Baffle Mount.dxf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]
2015-12-09 Corrected dxf whitespace
    [Back Face.dxf, Baffle Front Plate.dxf, Baffle Mount.dxf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]
2015-12-09 Rename "vectors" to "panels", use snake case names
    panels is a less confusing directory name than vectors which from
    feedback was deemed confusing due to its many other meanings. files
    names changed to snake case for consistency and better practice
    [Back Face.dxf, Baffle Front Plate.dxf, Baffle Spacer.dxf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]
2015-12-14 Large update to export script - some arcs still flipped
    Script now correctly exports all lines but arcs are sometimes flipped
    with no reliable 100% way of detecting when they need to be flipped back
    yet found. Lots of debug info added which is toggled by globals at top
    of file.
    [back_face.dxf, baffle_front_plate.dxf, baffle_mount.dxf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]
2015-12-14 Front frame arcs redrawn
    Arcs were corrupted so redrew
    [front_frame.dxf]
2015-12-14 Complete rewrite of arc logic - correctly renders all arcs
    No longer use start and end angles reported be Sketchup instead use
    start, end and mid points to calculate start and end angles ensuring
    they pass through the mid point - correctly renders all arcs.
    [back_face.dxf, baffle_front_plate.dxf, baffle_mount.dxf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]
2015-12-14 Fixed case where some polylines are not closed
    [back_face.dxf, baffle_front_plate.dxf, baffle_mount.dxf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]
2015-12-14 Added motor mounts to exported panels
    [nema_17_mount.dxf, nema_23_mount.dxf]
2015-12-14 Added logo front + back, corrected some panel axes
    [front_door.dxf, hdmi_support_1.dxf, hdmi_support_2.dxf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]
2015-12-15 Split out PSU to separate part
    [Part - PSU.skp]
2015-12-15 Split out flap servo to separate part
    [Part - Flap Servo.skp]
2015-12-15 Split out Raspberry Pi to separate part
    [Part - Raspberry Pi Model B.skp]
2015-12-15 Added parts to dxf export list
    Gave component names "Panel - ..." prefix to include them in export.
    Gantry spacer with captive nut slot added. Humidity chamber top face
    with holes for inlet and outlet tubes, filling port, and fogger power
    wire added. Removable humidity chamber support for easy removal of
    chamber for draining and cleaning added.
    [gantry_spacer.dxf, humidity_chamber_top_face.dxf, humidity_support.dxf]
2015-12-15 Rounded radii to 3d.p.
    All other measurements were already rounded to 3d.p. Radii updated to
    match. Should ensure dxfs only change when definition is changed rather
    than through floating point errors.
    [back_face.dxf, baffle_front_plate.dxf, baffle_mount.dxf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]
2015-12-15 Scripted exporting screenshots with names
    Exporting screenshots added to standard export procedure, switched to
    .png to support transparency , scripting allows for scene names to be
    used for filenames
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2015-12-16 Added DC motors and screenshots for other motors
    [dc_motor_mount.dxf]
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2015-12-22 Correct asymmetry in baffle outlines
    [baffle_mount.dxf, baffle_spacer.dxf]
2015-12-22 Reverted motor axis move
    Part of the redesign work had moved the lead screws closer together to
    better fit the NEMA 23 mounts on the top which required some redesign of
    the gantry. This commit attaches NEMA 23 in a way which does not require
    the lead screws to be moved so the existing instrument is much easier to
    bring up to date. The only downside is that the NEMA 23 mounting plate
    is not directly bolted to the vertical beams (this was an improvement on
    the current design which does not do this and it will still be possible
    to bolt the new DC motor and stepper motor plates to the verticals just
    not the NEMA 23). If this proves to be a problem then it would be
    trivial to make one if thicker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
    [dc_motor_mount.dxf, delrin_plate.dxf, gantry_spacer.dxf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]
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2015-12-23 Sort loops by length in dxf
    Trying to resolve dxfs files being exported differently without changes
    to the part where definitions are shuffled but not changed
    [back_face.dxf, baffle_front_plate.dxf, baffle_mount.dxf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]
2015-12-23 Fix Polygons
    Polygons return an ArcCurve object and so were being treated as such.
    Added a test for polygons to exclude them and instead render them as
    polylines.
    [gantry_spacer.dxf]
2015-12-27 Increased hole size in mounting plate
    Move to 3.2mm holes for mounting motor so panel can be cut with a 1/8th
    inch cutter
    [nema_17_mount.dxf]
2015-12-27 Increased clearance for central hole
    Fit was too tight around raised motor bezel
    [nema_23_mount.dxf]
2015-12-27 Widened slots to 3.2mm
    Widened slots to 3.2mm to accept real world thickness of 3mm sheet
    [heater_chamber_bottom.dxf]
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2015-12-28 Reworked rear module bottom
    Changed faces overlap, created clip in HDMI brackets
    [hdmi_support_1.dxf, hdmi_support_2.dxf, heater_chamber_bottom.dxf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]
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2015-12-31 Increased clearance for locking tabs on HDMI
    [hdmi_support_1.dxf, hdmi_support_2.dxf]
2015-12-31 Corrected raspberry pi connector slot size
    [rear_module_humidity_side.dxf]
2015-12-31 Added mounting holes for electronics assembly
    Refined electronics placement. Moved hole for fogger cable down, moved
    to supporting larger Arduino form factor eg. DUE as well as standard
    size. Using Due or Metro allows programming via right angle USBOTG
    cable.
    [rear_module_electronics.dxf, rear_module_humidity_side.dxf]
2016-01-01 Added hole for heater power, grouped humidity assembly
    [rear_module_electronics.dxf]
2016-01-01 Added USB OTG hole in side panel
    [rear_module_humidity_side.dxf]
2016-01-01 Renamed rear module faces to match naming convention
    [rear_module_bottom_face.dxf, rear_module_top_face.dxf]
2016-01-01 Tweaking positions based on first machining
    [rear_module_back_double_glazing.dxf, rear_module_bottom_face.dxf, rear_module_electronics.dxf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]
2016-01-01 Further position tweaks based on second machining
    [rear_module_bottom_face.dxf, rear_module_humidity_side.dxf]
2016-01-02 Added heater reflector plates
    [fan_mounting.dxf, heater_reflector_plate.dxf, rear_module_back_double_glazing.dxf]
2016-01-02 Large update - start of top enclosure and renaming
    [dc_motor_mount.dxf, humidity_end_cap.dxf, humidity_rubber_bumper_bottom.dxf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]
2016-01-02 Added cable and bolt holes in top faces
    [top_double_glazing_middle.dxf, top_module_bottom.dxf, top_module_side.dxf]
2016-01-03 Added touch screen
    [Part - DFROBOT USB Touch Screen.skp, top_module_front.dxf, top_module_side.dxf]
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2016-01-03 Added temp sensors top and bottom of rear module
    [rear_module_top_and_bottom_double_glazing.dxf]
2016-01-03 Corrected slot in rear module double glazing
    Slot needed to be longer for temp sensors to clear fan mounting plate
    [rear_module_top_and_bottom_double_glazing.dxf]
2016-01-03 Fix for oscillations around target after move
    [dc_motors.ino]
2016-01-04 Shrink top module to just enclose motor electronics
    (not with DFrobot screen
    [top_module_back.dxf, top_module_side.dxf]
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2017-09-15 Added printed load cell mount
    Ideally this bracket for the load cell should be machined from metal - but my hope is that these printed parts are stiff enough to get started with, until it's possible to get proper metal ones made.
    [load_cell_mount.scad, load_cell_mount.stl, load_cell_mount_compression.stl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]
2017-09-20 added spacers
    [load_cell_spacer_M3.scad, load_cell_spacer_M3.stl]
